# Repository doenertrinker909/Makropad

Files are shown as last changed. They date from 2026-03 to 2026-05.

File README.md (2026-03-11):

# Makropad

A minimalistic makropad featuring a 4x4 grid of keys, two rotary encoders and a 128x32 OLED display. 

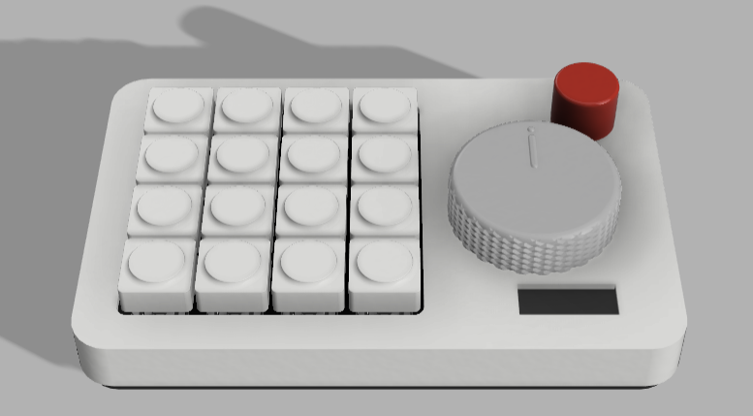
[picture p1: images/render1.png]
render of the makropad


You can put most makropad-like keyboards in two categories:

Way too expensive and overbloated with useless features

or

An ok price but an ugly design (in my opinion)

That's what motivated me to make my own makropad. It's designed to be easily built, having just the right amount of features all while having a sleek minimalistic design.

# Features

- Arduino Pro Micro MCU (ATmega32u4)
- Two customizable rotary encoders
- A 128x32 OLED that displays helpful information
- Custom shortcuts for any program (with QMK)
- Power via USB-C
- Sleek minimalistic case optimised for CNC milling and 3D printing
- Hot swap switches

# PCB

The pcb layout

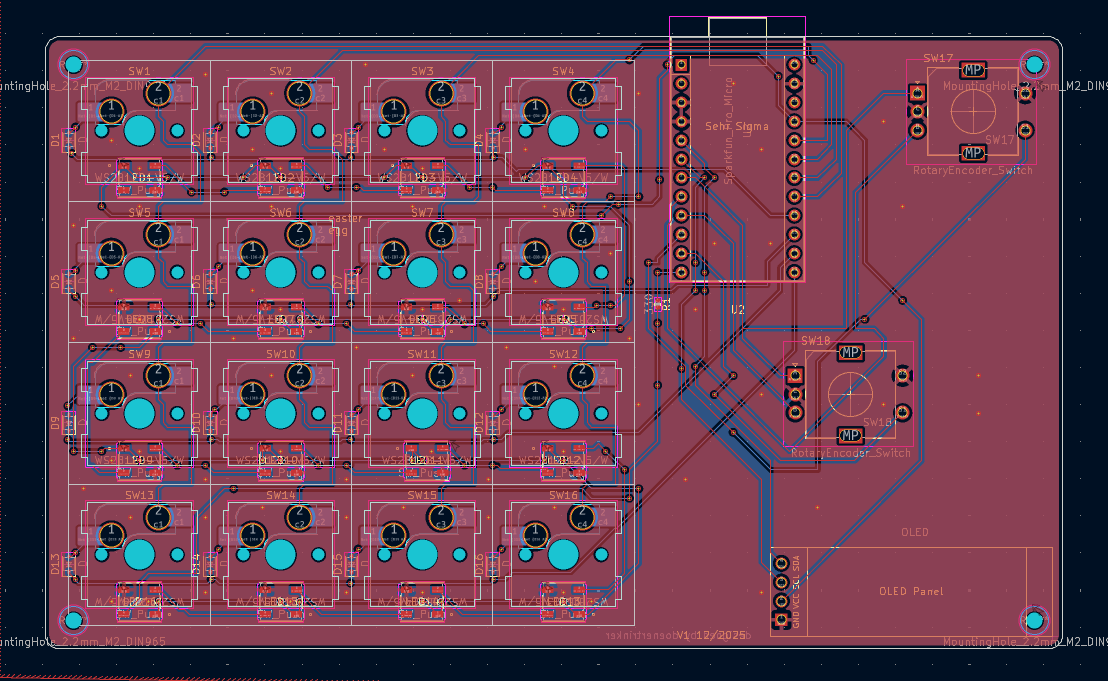
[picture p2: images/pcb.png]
screenshot of the pcb layout


<details>
  <summary> The schematics </summary>
  
  The MCU with the encoders and OLED

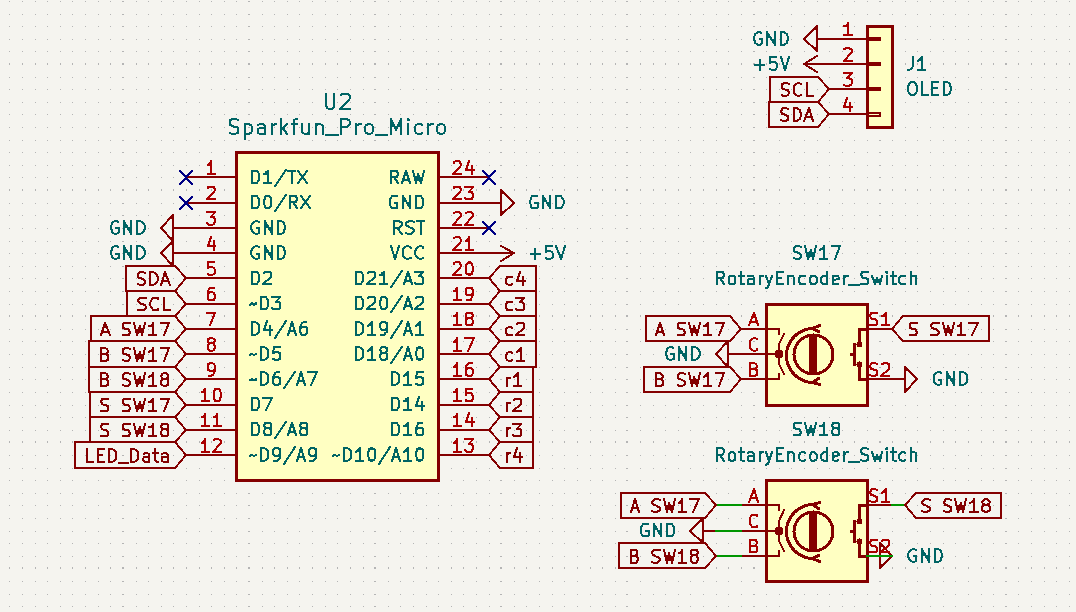
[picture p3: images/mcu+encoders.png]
image of mcu + encoders
  

  The switch matrix

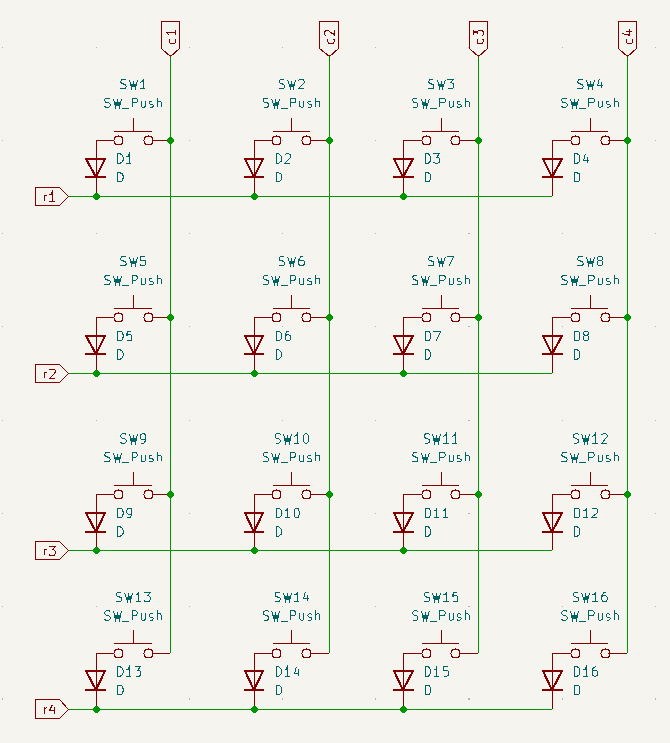
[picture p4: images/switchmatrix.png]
image of the switch matrix
  

  The LED matrix

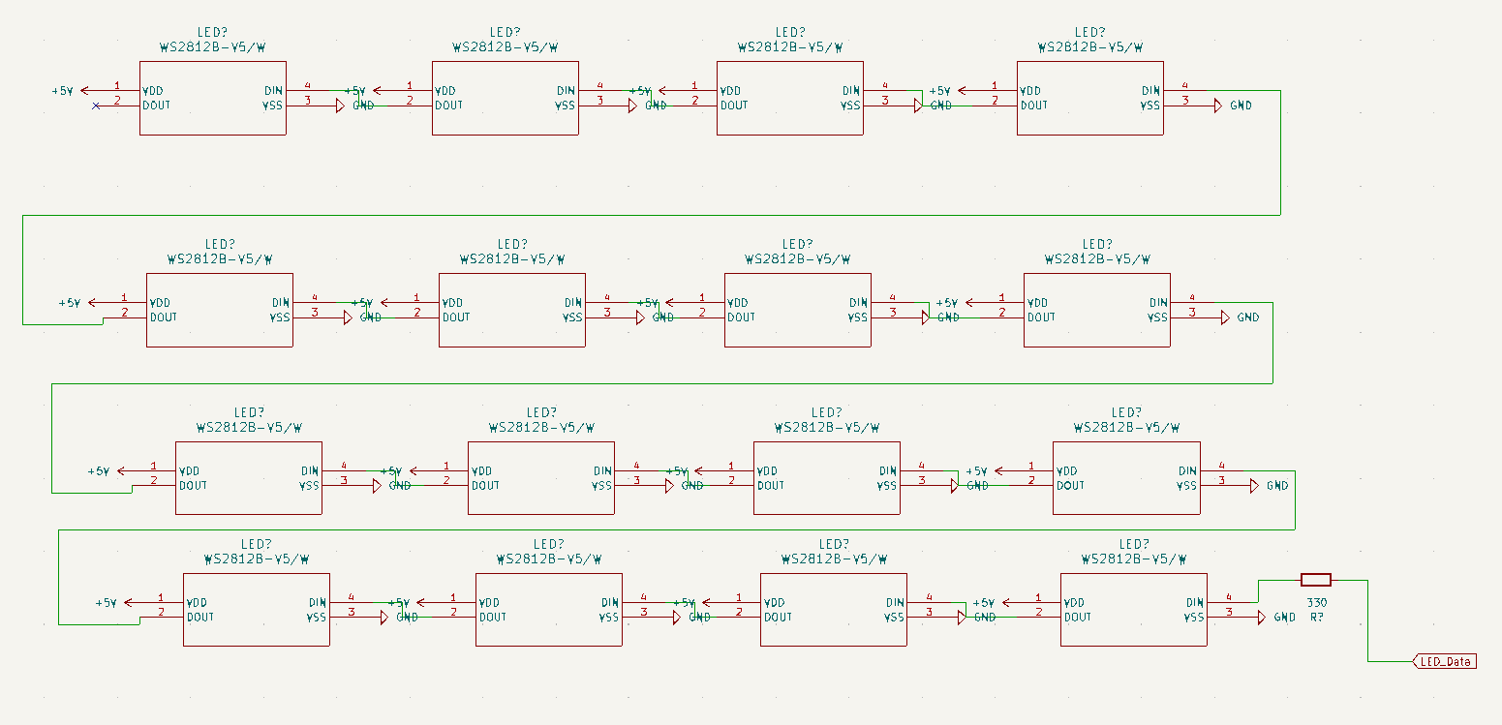
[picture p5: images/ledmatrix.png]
image of the led matrix
  
</details>

# First start

- By default the makropad will work like a standard numpad in the following format:

<kbd> 7 </kbd> <kbd> 8 </kbd> <kbd> 9 </kbd> <kbd> + </kbd>

<kbd> 4 </kbd> <kbd> 5 </kbd> <kbd> 6 </kbd> <kbd> - </kbd>

<kbd> 1 </kbd> <kbd> 2 </kbd> <kbd> 3 </kbd> <kbd> * </kbd>

<kbd> 0 </kbd> <kbd> . </kbd> <kbd> / </kbd> <kbd> ↵ </kbd>

- You can either just compile and flash the firmware with QMK toolbox or choose to customize the code further to your needs
- By customizing the QMK files you can make it your own

# BOM

This is an estimated cost:
| Product Name | Product Description | Product Link | Product Unit Cost in EUR | Product Amount | Total in EUR |
|:---|:---|:---|:---|:---|---:|
| 1N4148WS | Diode SOD-323 | https://jlcpcb.com/partdetail/2485-1N4148WS/C2128 | 0.0079 | 16.0 | 0.13 |
| - | 128x32 OLED | https://www.amazon.de/-/en/gp/product/B07BDFXFRK | 4.5 | 1.0 | 4.5  |
| WS2812B-V5/W | LED 5050 | https://jlcpcb.com/partdetail/Worldsemi-WS2812B_V5W/C2874885 | 0.09 | 16.0 | 1.34 |
| RCA02330RJLF | 330 Ohm resistor 0402 | https://jlcpcb.com/partdetail/23789673-RCA02330RJLF/C22356229 | 0.0003 | 1.0 | 0 |
| CHERRY MX2A-71NN | Cherry style keyboardswitch | https://www.reichelt.de/de/de/shop/produkt/cherry_mx_silent_red_-_tastenmodul_-_schnappbefestigung-361531 | 0.75 | 16.0 | 12 |
| - | EC11 Rotary encoder | https://www.amazon.de/-/en/gp/product/B08728PS6N | 2.0 | 2.0 | 4 |
| ARD PRO-MICRO-C | Arduino Pro Micro (ATmega32u4) | https://www.reichelt.de/de/de/shop/produkt/arduino_-_mikrocontroller_atmega32u4_usb-c-421607 | 7.99 | 1.0 | 7.99 |
| YMDK Kailh CPG151101S11 | Kailh Hotswap Sockets | https://www.amazon.de/-/en/YMDK-CPG151101S11-Swappable-Mechanical-Keyboards/dp/B07K8CCMQZ | 0.16 | 16.0 | 2.56 |
| | | | | | 32.52 |

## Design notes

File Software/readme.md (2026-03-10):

# jjj_makropad

jjj_makropad

*A short description of the keyboard/project*

* Keyboard Maintainer: [Jonas](https://github.com/doenertrinker909)
* Hardware Supported: *The PCBs, controllers supported*
* Hardware Availability: *Links to where you can find this hardware*

Make example for this keyboard (after setting up your build environment):

    make jjj_makropad:default

Flashing example for this keyboard:

    make jjj_makropad:default:flash

See the [build environment setup](https://docs.qmk.fm/#/getting_started_build_tools) and the [make instructions](https://docs.qmk.fm/#/getting_started_make_guide) for more information. Brand new to QMK? Start with our [Complete Newbs Guide](https://docs.qmk.fm/#/newbs).

## Bootloader

Enter the bootloader in 3 ways:

* **Bootmagic reset**: Hold down the key at (0,0) in the matrix (usually the top left key or Escape) and plug in the keyboard
* **Physical reset button**: Briefly press the button on the back of the PCB - some may have pads you must short instead
* **Keycode in layout**: Press the key mapped to `QK_BOOT` if it is available

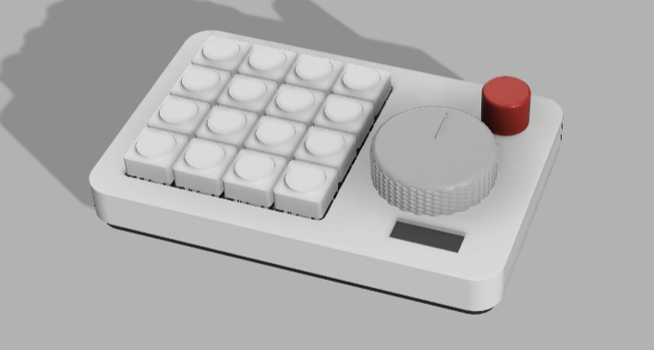
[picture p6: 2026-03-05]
images/render2.png

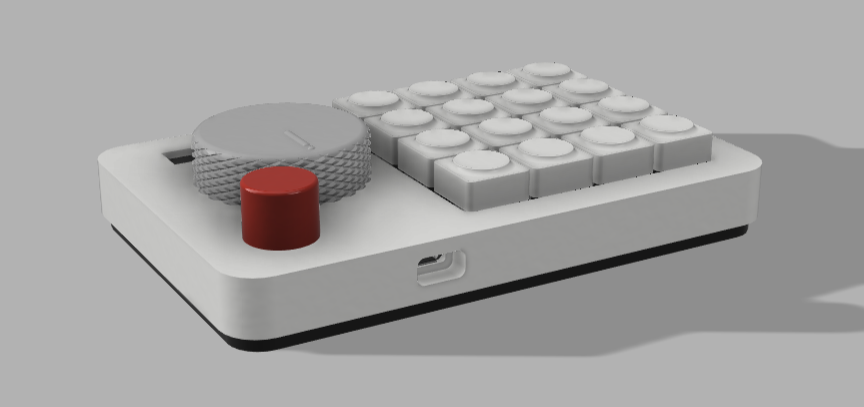
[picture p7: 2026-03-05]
images/render3.png

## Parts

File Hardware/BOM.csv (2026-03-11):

Product Name | Product Description | Product Link | Product Unit Cost in EUR | Product Amount | Total in EUR
1N4148WS | Diode SOD-323 | https://jlcpcb.com/partdetail/2485-1N4148WS/C2128 | 0.0079 | 16 | 0.13
- | 128x32 OLED | https://www.amazon.de/-/en/gp/product/B07BDFXFRK | 4.5 | 1 | 4.5
WS2812B-V5/W | LED 5050 | https://jlcpcb.com/partdetail/Worldsemi-WS2812B_V5W/C2874885 | 0.09 | 16 | 1.34
RCA02330RJLF | 330 Ohm resistor 0402 | https://jlcpcb.com/partdetail/23789673-RCA02330RJLF/C22356229 | 0.0003 | 1 | 0
CHERRY MX2A-71NN | Cherry style keyboardswitch | https://www.reichelt.de/de/de/shop/produkt/cherry_mx_silent_red_-_tastenmodul_-_schnappbefestigung-361531 | 0.75 | 16 | 12
- | EC11 Rotary encoder | https://www.amazon.de/-/en/gp/product/B08728PS6N | 2.0 | 2 | 4.0
ARD PRO-MICRO-C | Arduino Pro Micro (ATmega32u4) | https://www.reichelt.de/de/de/shop/produkt/arduino_-_mikrocontroller_atmega32u4_usb-c-421607 | 7.99 | 1 | 7.99
YMDK Kailh CPG151101S11 | Kailh Hotswap Sockets | https://www.amazon.de/-/en/YMDK-CPG151101S11-Swappable-Mechanical-Keyboards/dp/B07K8CCMQZ | 0.16 | 16 | 2.56
 |  |  |  |  | 32.52

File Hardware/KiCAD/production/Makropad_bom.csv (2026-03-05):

Designator | Footprint | Quantity | Value | LCSC Part #
D1, D10, D11, D12, D13, D14, D15, D16, D2, D3, D4, D5, D6, D7, D8, D9 | D_SOD-323 | 16 | D
J1 | SSD1306-0.91-OLED-4pin-128x32 | 1 | OLED
LED1, LED10, LED11, LED12, LED13, LED14, LED15, LED16, LED2, LED3, LED4, LED5, LED6, LED7, LED8, LED9 | SMD4_LED_SMD5050_WS2812B_WDS | 16 | WS2812B-V5/W
R1 | 0402 | 1 | 330
SW1, SW10, SW11, SW12, SW13, SW14, SW15, SW16, SW2, SW3, SW4, SW5, SW6, SW7, SW8, SW9 | SW_Hotswap_Kailh_MX_Plated_1.00u | 16 | SW_Push
SW17, SW18 | RotaryEncoder_Alps_EC11E-Switch_Vertical_H20mm | 2 | RotaryEncoder_Switch
U2 | Sparkfun_Pro_Micro | 1 | Sparkfun_Pro_Micro

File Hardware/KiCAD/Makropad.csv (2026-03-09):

Reference | Qty | Value | DNP | Exclude from BOM | Exclude from Board | Footprint | Datasheet
D1,D2,D3,D4,D5,D6,D7,D8,D9,D10,D11,D12,D13,D14,D15,D16 | 16 | D |  |  |  | Diode_SMD:D_SOD-323 | ~
J1 | 1 | OLED |  |  |  | OLED:SSD1306-0.91-OLED-4pin-128x32 | ~
LED1,LED2,LED3,LED4,LED5,LED6,LED7,LED8,LED9,LED10,LED11,LED12,LED13,LED14,LED15,LED16 | 16 | WS2812B-V5/W |  |  |  | WS2812B-V5/W:SMD4_LED_SMD5050_WS2812B_WDS | WS2812B-V5/W
R1 | 1 | 330 |  |  |  | Resistor_SMD:R_0402_1005Metric | ~
SW1,SW2,SW3,SW4,SW5,SW6,SW7,SW8,SW9,SW10,SW11,SW12,SW13,SW14,SW15,SW16 | 16 | SW_Push |  |  |  | PCM_Switch_Keyboard_Hotswap_Kailh:SW_Hotswap_Kailh_MX_Plated_1.00u | ~
SW17,SW18 | 2 | RotaryEncoder_Switch |  |  |  | Rotary_Encoder:RotaryEncoder_Alps_EC11E-Switch_Vertical_H20mm | ~
U2 | 1 | Sparkfun_Pro_Micro |  |  |  | ArduinoPro:Sparkfun_Pro_Micro | https://www.sparkfun.com/products/12640

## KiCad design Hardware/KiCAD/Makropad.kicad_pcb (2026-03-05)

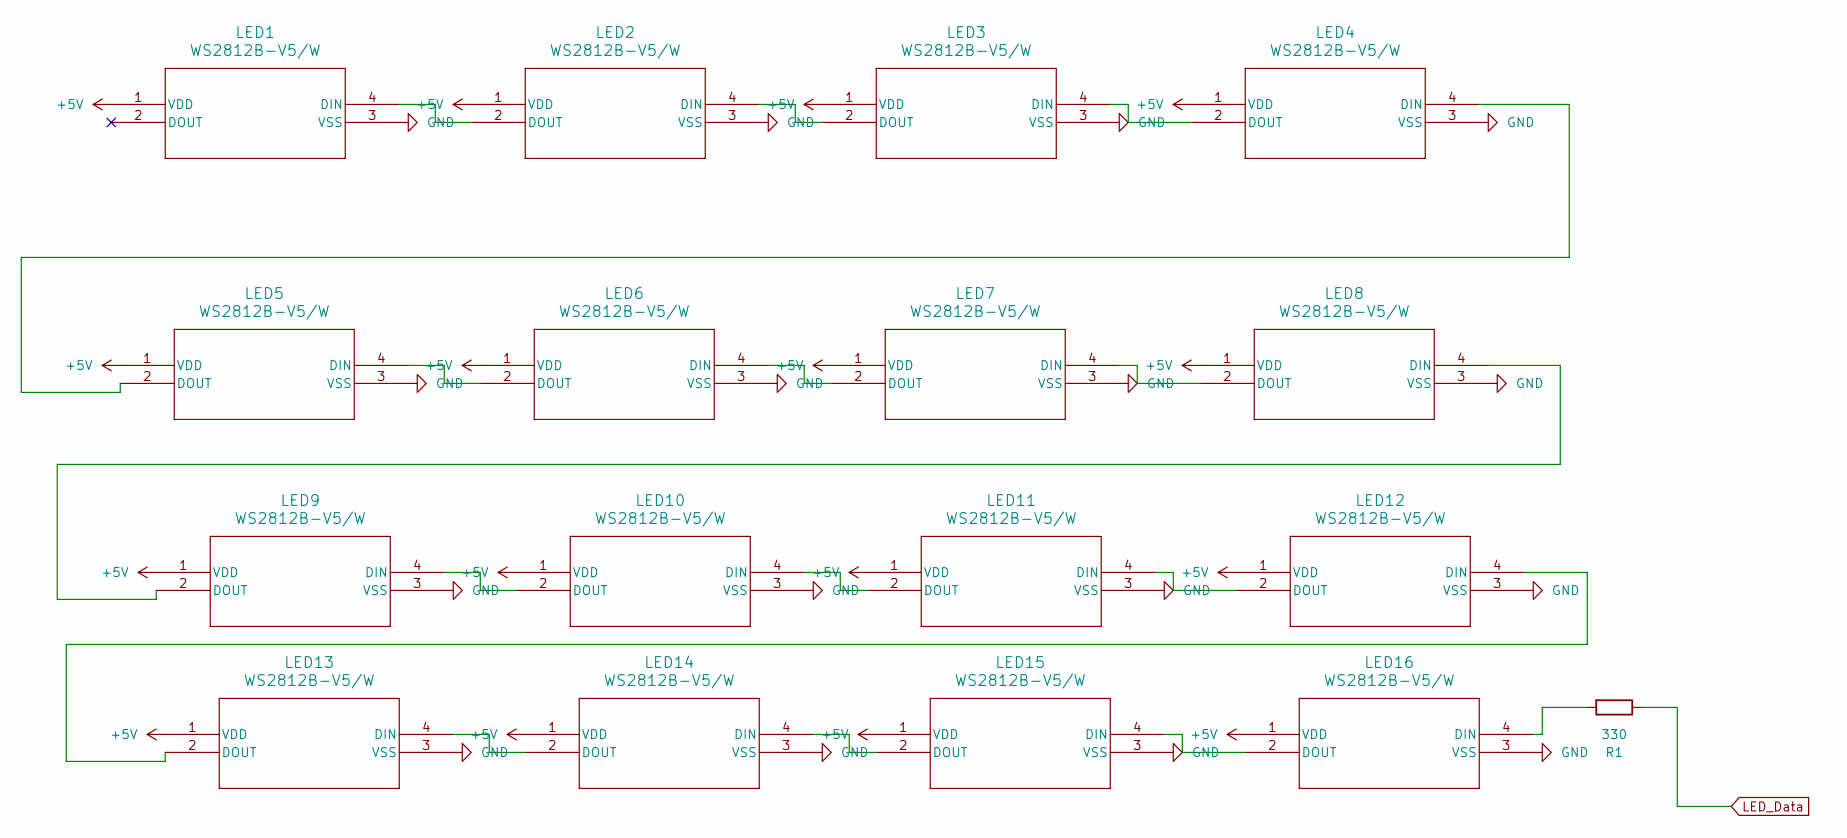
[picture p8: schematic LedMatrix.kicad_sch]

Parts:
LED1, LED2, LED3, LED4, LED5, LED6, LED7, LED8, LED9, LED10, LED11, LED12, LED13, LED14, LED15, LED16: WS2812B-V5/W; SMD4_LED_SMD5050_WS2812B_WDS
R1: 330; R_0402_1005Metric

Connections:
+5V: LED1.1 (VDD), LED2.1 (VDD), LED3.1 (VDD), LED4.1 (VDD), LED5.1 (VDD), LED6.1 (VDD), LED7.1 (VDD), LED8.1 (VDD), LED9.1 (VDD), LED10.1 (VDD), LED11.1 (VDD), LED12.1 (VDD), LED13.1 (VDD), LED14.1 (VDD), LED15.1 (VDD), LED16.1 (VDD); also elsewhere on the board
GND: LED1.3 (VSS), LED2.3 (VSS), LED3.3 (VSS), LED4.3 (VSS), LED5.3 (VSS), LED6.3 (VSS), LED7.3 (VSS), LED8.3 (VSS), LED9.3 (VSS), LED10.3 (VSS), LED11.3 (VSS), LED12.3 (VSS), LED13.3 (VSS), LED14.3 (VSS), LED15.3 (VSS), LED16.3 (VSS); also elsewhere on the board
LED_Data: R1.1; also elsewhere on the board
unnamed: LED1.4 (DIN), LED2.2 (DOUT)
unnamed: LED2.4 (DIN), LED3.2 (DOUT)
unnamed: LED3.4 (DIN), LED4.2 (DOUT)
unnamed: LED4.4 (DIN), LED5.2 (DOUT)
unnamed: LED5.4 (DIN), LED6.2 (DOUT)
unnamed: LED6.4 (DIN), LED7.2 (DOUT)
unnamed: LED7.4 (DIN), LED8.2 (DOUT)
unnamed: LED8.4 (DIN), LED9.2 (DOUT)
unnamed: LED10.4 (DIN), LED11.2 (DOUT)
unnamed: LED9.4 (DIN), LED10.2 (DOUT)
unnamed: LED11.4 (DIN), LED12.2 (DOUT)
unnamed: LED12.4 (DIN), LED13.2 (DOUT)
unnamed: LED13.4 (DIN), LED14.2 (DOUT)
unnamed: LED14.4 (DIN), LED15.2 (DOUT)
unnamed: LED15.4 (DIN), LED16.2 (DOUT)
unnamed: LED16.4 (DIN), R1.2

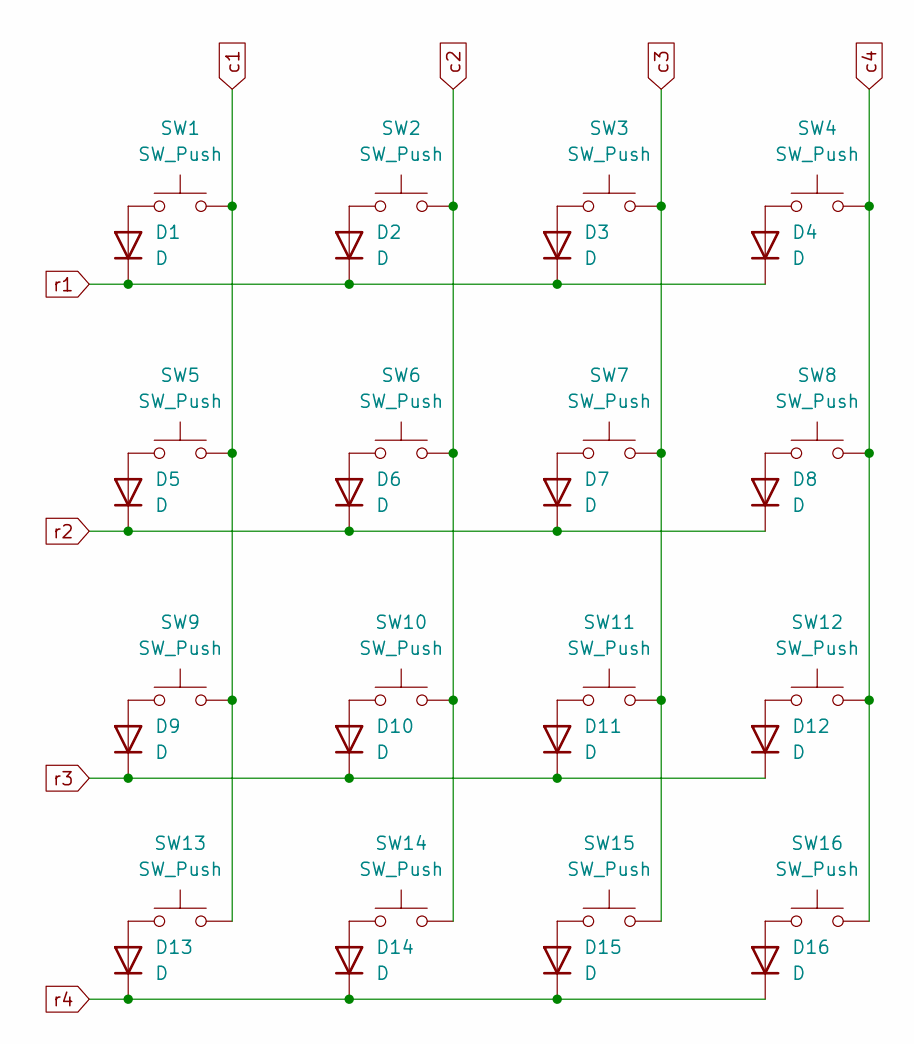
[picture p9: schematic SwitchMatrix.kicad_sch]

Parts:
D1, D2, D3, D4, D5, D6, D7, D8, D9, D10, D11, D12, D13, D14, D15, D16: D; D_SOD-323
SW1, SW2, SW3, SW4, SW5, SW6, SW7, SW8, SW9, SW10, SW11, SW12, SW13, SW14, SW15, SW16: SW_Push; SW_Hotswap_Kailh_MX_Plated_1.00u

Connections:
unnamed: D1.2 (A), SW1.1
unnamed: D2.2 (A), SW2.1
unnamed: D3.2 (A), SW3.1
unnamed: D4.2 (A), SW4.1
unnamed: D5.2 (A), SW5.1
unnamed: D6.2 (A), SW6.1
unnamed: D7.2 (A), SW7.1
unnamed: D8.2 (A), SW8.1
unnamed: D9.2 (A), SW9.1
unnamed: D10.2 (A), SW10.1
unnamed: D11.2 (A), SW11.1
unnamed: D12.2 (A), SW12.1
unnamed: D13.2 (A), SW13.1
unnamed: D14.2 (A), SW14.1
unnamed: D15.2 (A), SW15.1
unnamed: D16.2 (A), SW16.1
c1: SW1.2, SW5.2, SW9.2, SW13.2; also elsewhere on the board
c2: SW2.2, SW6.2, SW10.2, SW14.2; also elsewhere on the board
c3: SW3.2, SW7.2, SW11.2, SW15.2; also elsewhere on the board
c4: SW4.2, SW8.2, SW12.2, SW16.2; also elsewhere on the board
r1: D1.1 (K), D2.1 (K), D3.1 (K), D4.1 (K); also elsewhere on the board
r2: D5.1 (K), D6.1 (K), D7.1 (K), D8.1 (K); also elsewhere on the board
r3: D9.1 (K), D10.1 (K), D11.1 (K), D12.1 (K); also elsewhere on the board
r4: D13.1 (K), D14.1 (K), D15.1 (K), D16.1 (K); also elsewhere on the board

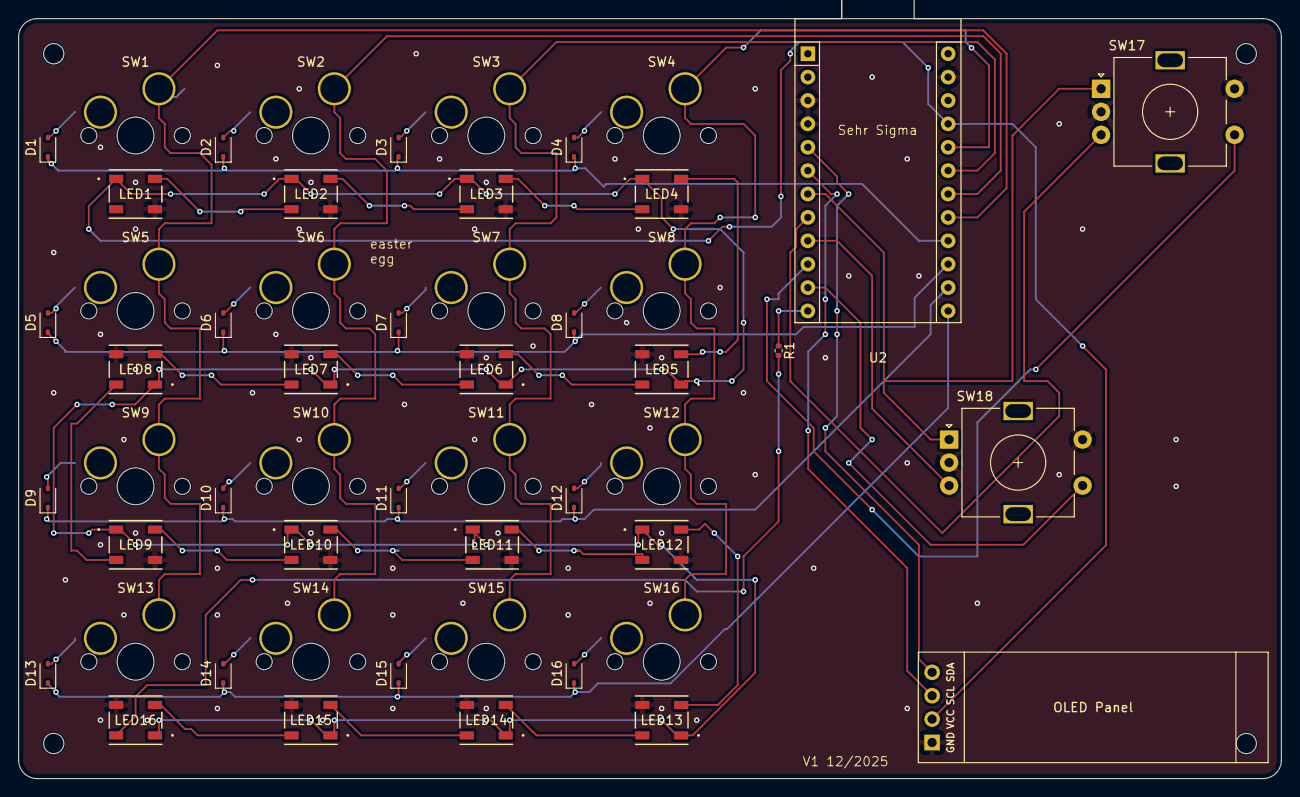
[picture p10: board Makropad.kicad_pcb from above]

Board: 2 copper layers, 137.2 x 82.6 mm, 53 parts (0 on the bottom side), 50 nets.

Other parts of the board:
J1: OLED; SSD1306-0.91-OLED-4pin-128x32
SW17, SW18: RotaryEncoder_Switch; RotaryEncoder_Alps_EC11E-Switch_Vertical_H20mm
U2: Sparkfun_Pro_Micro

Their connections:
+5V: J1.2, U2.21 (VCC); also elsewhere on the board
A SW17: SW17.A, SW18.A, U2.7 (D4/A6)
B SW17: SW17.B, U2.8 (~D5)
B SW18: SW18.B, U2.9 (~D6/A7)
GND: J1.1, SW17.C, SW17.S2, SW18.C, SW18.S2, U2.3 (GND), U2.4 (GND), U2.23 (GND); also elsewhere on the board
LED_Data: U2.12 (~D9/A9); also elsewhere on the board
S SW17: SW17.S1, U2.10 (D7)
S SW18: SW18.S1, U2.11 (D8/A8)
SCL: J1.3, U2.6 (~D3)
SDA: J1.4, U2.5 (D2)
c1: U2.17 (D18/A0); also elsewhere on the board
c2: U2.18 (D19/A1); also elsewhere on the board
c3: U2.19 (D20/A2); also elsewhere on the board
c4: U2.20 (D21/A3); also elsewhere on the board
r1: U2.16 (D15); also elsewhere on the board
r2: U2.15 (D14); also elsewhere on the board
r3: U2.14 (D16); also elsewhere on the board
r4: U2.13 (~D10/A10); also elsewhere on the board

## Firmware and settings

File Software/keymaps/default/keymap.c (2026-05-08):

// Copyright 2023 QMK
// SPDX-License-Identifier: GPL-2.0-or-later

#include QMK_KEYBOARD_H
uint16_t oled_timer = 0;
bool show_splash = false;

enum my_layers {
    _BASE,
    _LED,
    _DEBUGL,
};

const uint16_t PROGMEM keymaps[][MATRIX_ROWS][MATRIX_COLS] = {

    [_BASE] = LAYOUT_numpad_4x4(
        KC_P7,   KC_P8,   KC_P9,   KC_PPLS,
        KC_P4,   KC_P5,   KC_P6,   KC_PMNS,
        KC_P1,   KC_P2,   KC_P3,   KC_PAST,
        KC_P0,   KC_PDOT, KC_PSLS, KC_PENT
    ),
    [_LED] = LAYOUT_numpad_4x4(
        KC_NO,   KC_NO,   RM_HUED,   RM_HUEU,
        KC_NO,   KC_NO,   RM_SATD,   RM_SATU,
        KC_NO,   KC_NO,   RM_VALD,   RM_VALU,
        RM_PREV, RM_NEXT, RM_SPDD,   RM_SPDU
    ),
    [_DEBUGL] = LAYOUT_numpad_4x4(
        KC_NO,   KC_NO,   KC_NO,   KC_NO,
        KC_NO,   KC_NO,   KC_NO,   KC_NO,
        KC_NO,   KC_NO,   KC_NO,   KC_NO,
        KC_NO,   KC_NO,   QK_RBT,   QK_BOOT
    )

};
#if defined(ENCODER_MAP_ENABLE)
const uint16_t PROGMEM encoder_map[][NUM_ENCODERS][NUM_DIRECTIONS] = {
    [_BASE]   = { ENCODER_CCW_CW(KC_VOLU, KC_VOLD), ENCODER_CCW_CW(MS_WHLU, MS_WHLD) },
    [_LED]    = { ENCODER_CCW_CW(KC_TRNS, KC_TRNS), ENCODER_CCW_CW(KC_TRNS, KC_TRNS) },
    [_DEBUGL] = { ENCODER_CCW_CW(KC_TRNS, KC_TRNS), ENCODER_CCW_CW(KC_TRNS, KC_TRNS) }
};
#endif

led_config_t g_led_config = { {
  // Key Matrix to LED Index
    {   15, 14, 13, 12 },
    {    8,  9, 10, 11 },
    {    7,  6,  5,  4 },
    {    0,  1,  2,  3 }
}, {
  // LED Index to Physical Position (X, Y)
    { 0, 64 }, { 75, 64 }, { 149, 64 }, { 224, 64 }, // 0 bis 3
    { 224, 43 }, { 149, 43 }, { 75, 43 }, { 0, 43 }, // 4 bis 7
    { 0, 21 }, { 75, 21 }, { 149, 21 }, { 224, 21 }, // 8 bis 11
    { 224, 0 }, { 149, 0 }, { 75, 0 }, { 0, 0 }      // 12 bis 15
}, {
    // LED Index to Flag (1 = Underglow, 4 = Key Backlight)
    4, 4, 4, 4, 4, 4, 4, 4, 4, 4, 4, 4, 4, 4, 4, 4
} };

layer_state_t layer_state_set_user(layer_state_t state) {
    oled_timer = timer_read(); // Aktuelle Zeit speichern
    if (!show_splash) {
        oled_clear(); // Altes Menü sofort löschen, damit nichts überlappt
    }
    show_splash = true; 
    return state;
}

#ifdef OLED_ENABLE
bool oled_task_user(void) {
    if (show_splash) {
        // Prüfen, ob schon 3000 ms (3 Sekunden) vergangen sind
        if (timer_elapsed(oled_timer) < 3000) {
            
            // Cursor für den Splash-Screen zwingend auf Start setzen
            oled_set_cursor(0, 0); 
            
            // Aktuellen Layer anzeigen (mit Leerzeichen auffüllen zum Überschreiben)
            oled_write_P(PSTR("Layer: "), false);
            switch (get_highest_layer(layer_state)) {
                case _BASE:
                    oled_write_ln_P(PSTR("Base        "), false);
                    break;
                case _LED:
                    oled_write_ln_P(PSTR("LED Config  "), false);
                    break;
                case _DEBUGL:
                    oled_write_ln_P(PSTR("Debug       "), false);
                    break;
                default:
                    oled_write_ln_P(PSTR("Unbekannt   "), false);
                    break;
            }
            
            // Wichtig: Hier abbrechen! Das normale Menü soll noch NICHT gezeichnet werden.
            return false; 
            
        } 
        else {
            // Die 3 Sekunden sind vorbei!
            show_splash = false; // Splash-Screen ausschalten
            oled_clear(); 
            return false;       // Display EINMAL leeren, um Reste des Splash-Screens zu löschen
        }
    }

    // Cursor für das Standard-Menü auf Start setzen
    oled_set_cursor(0, 0);

    // Keymap menu
    uint8_t current_layer = get_highest_layer(layer_state);
    switch (current_layer) {
        case _BASE:{
            oled_write_ln_P(PSTR("   7    8    9    +  "), false);
            oled_write_ln_P(PSTR("   4    5    6    -  "), false);
            oled_write_ln_P(PSTR("   1    2    3    *  "), false);
            oled_write_ln_P(PSTR("   0    .    /   ENT "), false);
            break;}
        case _LED:{
            uint8_t mode = rgb_matrix_get_mode();
            char buf[22];
            // Formatierung als exakt eine Zeile, um alte Zeichen zu löschen
            snprintf(buf, sizeof(buf), " Mode: %-13d", mode); 
            oled_write_ln(buf, false);

            oled_write_ln_P(PSTR("           SAT- SAT+ "), false);
            oled_write_ln_P(PSTR("           BRI- BRI+ "), false);
            oled_write_ln_P(PSTR(" MOD- MOD+ SPD- SPD+ "), false);
            break;}
        case _DEBUGL:{
            oled_write_ln_P(PSTR("                     "), false);
            oled_write_ln_P(PSTR("                     "), false);
            oled_write_ln_P(PSTR("                     "), false);
            oled_write_ln_P(PSTR("           RBT  BOOT "), false);
            break;}
        default:{
            break;}
    }
    
    return false;
}
#endif

void keyboard_post_init_user(void) {
    // Pins als Eingänge mit Pull-up-Widerstand definieren  
    setPinInputHigh(E6); // Pin für Encoder-Knopf 1
    setPinInputHigh(B4); // Pin für Encoder-Knopf 2
}

void matrix_scan_user(void) {
    // --- Encoder 1 ---
    static bool btn1_pressed = false;
    bool is_low1 = !readPin(E6); // Pin wird bei Druck gegen GND gezogen

    if (is_low1 && !btn1_pressed) {
        register_code(KC_MUTE); // Aktion beim Drücken
        btn1_pressed = true;
    } else if (!is_low1 && btn1_pressed) {
        unregister_code(KC_MUTE); // Aktion beim Loslassen
        btn1_pressed = false;
    }

    // --- Encoder 2 (Layer hochwechseln) ---
    static bool btn2_pressed = false;
    bool is_low2 = !readPin(B4); // Pin anpassen!

    if (is_low2 && !btn2_pressed) {
        // 1. Aktuellen Layer auslesen
        uint8_t current_layer = get_highest_layer(layer_state);
        
        // 2. Einen Layer addieren
        uint8_t next_layer = current_layer + 1;

        // 3. Wenn das Maximum überschritten wird, wieder auf Layer 0 (Base) springen.
        // WICHTIG: Wenn Sie z. B. 3 Layer haben (0, 1, 2), ändern Sie die 1 in eine 2!
        if (next_layer > 2) { 
            next_layer = 0;
        }

        // 4. Den neuen Layer aktivieren
        layer_move(next_layer); 

        btn2_pressed = true;
    } else if (!is_low2 && btn2_pressed) {
        // Beim Loslassen müssen wir nichts tun, da der Layer dauerhaft 
        // gewechselt bleiben soll, bis man wieder drückt.
        btn2_pressed = false;
    }
}
